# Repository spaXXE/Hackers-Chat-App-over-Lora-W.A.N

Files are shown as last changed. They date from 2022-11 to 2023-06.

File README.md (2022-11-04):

# Under rigorous Development...

***
### Watch out for exclusive tech. coming your way😎!

***

```py
    import time 

    def development():
        
        while 1:
            time.delay()
            break # DISCLAIMER: Heads up, will break soon...

    development()
```
***

***

   ### As an appetiser, we humbly offer you.....

***

## The Project's Structure.

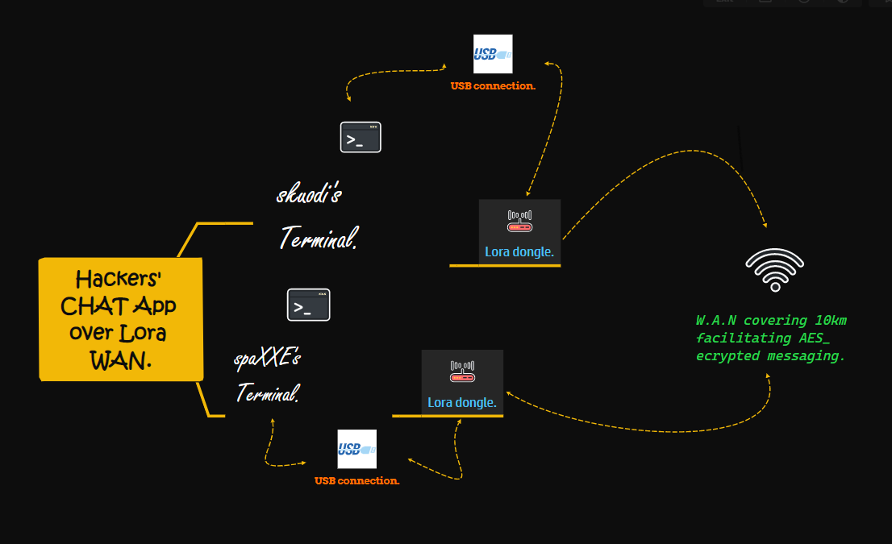
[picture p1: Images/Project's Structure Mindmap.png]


## The Sofware's Components and Structure Model.

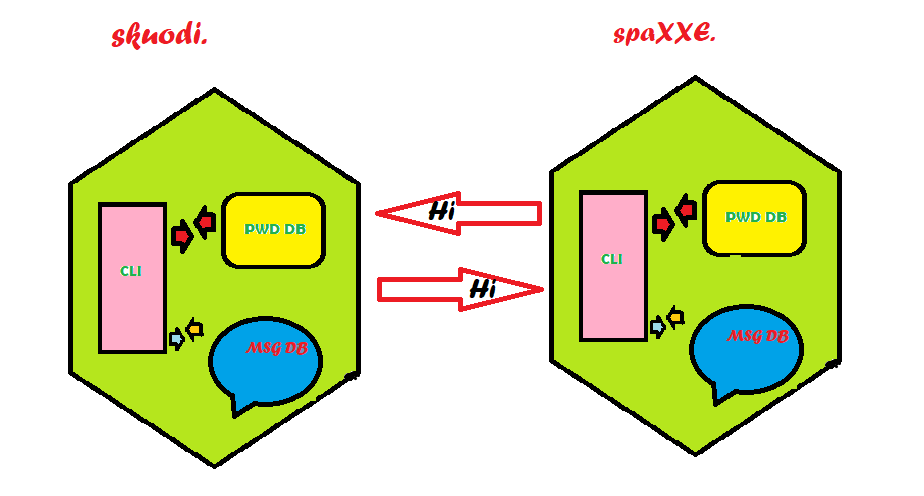
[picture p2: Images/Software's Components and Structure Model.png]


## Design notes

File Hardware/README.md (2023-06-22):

# LoRa Dongle

The hardware is a USB 2.0 fullspeed device with an STM32F042K6 MCU and 433MHz LoRa module based on the SX1278. Onboard EEPROM memory provides persistent storage of received messages and buffering of sent messages that have not been acknowledged to have been received by the sender.

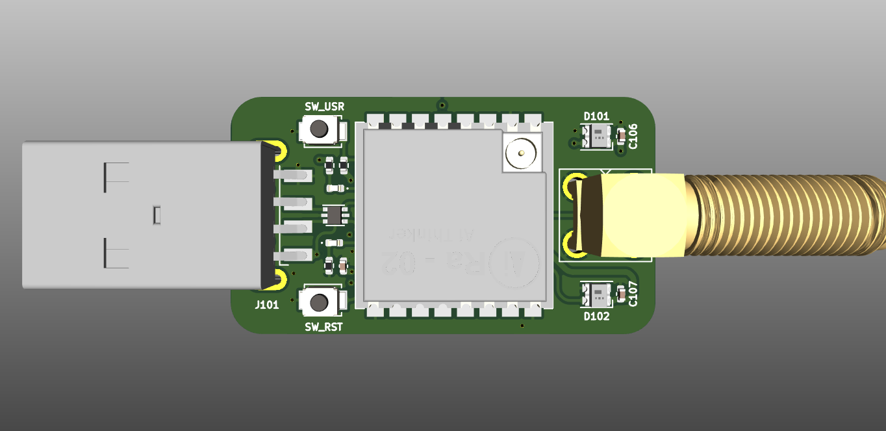
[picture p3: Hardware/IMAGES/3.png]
LoRa Dongle Top


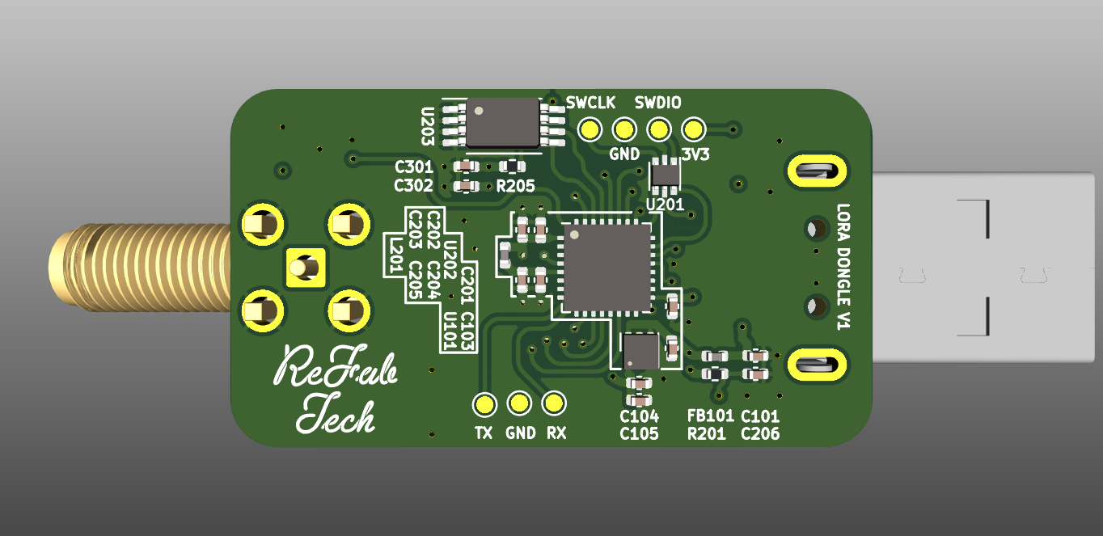
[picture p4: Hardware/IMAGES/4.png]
LoRa Dongle Top LoRa Dongle Bottom


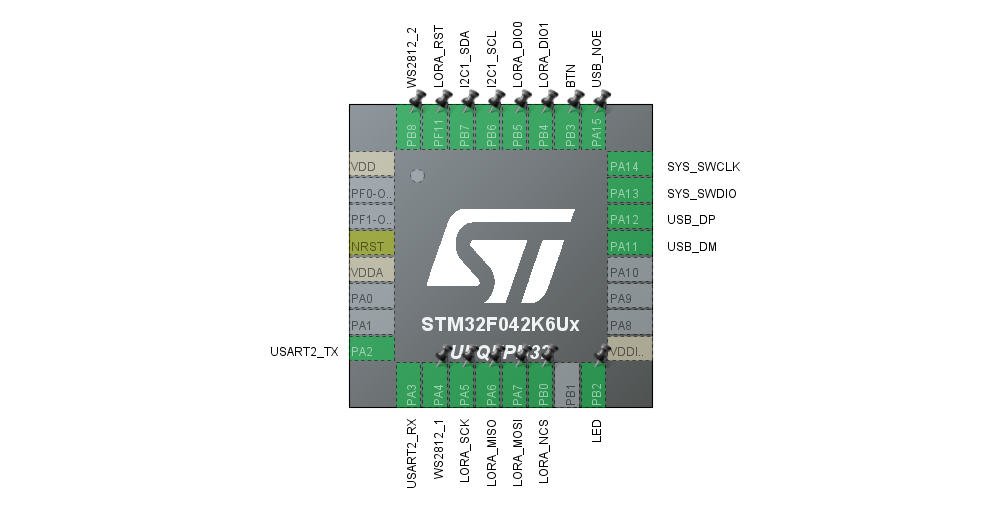
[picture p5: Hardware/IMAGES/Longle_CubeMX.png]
LoRa Dongle Top LoRa Dongle STM32 Pinout


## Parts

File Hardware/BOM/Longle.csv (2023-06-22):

Reference | Value | Footprint | MANUFACTURER | MPN | UNIT PRICE | VENDOR | Qty | TOTAL
AE301 | Antenna_Shield | Connector_Coaxial:SMA_Amphenol_901-143_Horizontal | BAT WIRELESS | BWSMA-KWE-Z001 | 0.4407 | LCSC | 1 | 0.4407
C101-C104, C203, C204, C206, C301 | 2u2 | Capacitor_SMD:C_0402_1005Metric | Samsung Electro-Mechanics | CL05A225MP5NSNC | 0.0038 | LCSC | 8 | 0.0304
C105-C107, C201, C202, C205, C302 | 100n | Capacitor_SMD:C_0402_1005Metric | CCTC | TCC0402X7R104K160AT | 0.0009 | LCSC | 7 | 0.0063
D101, D102 | WS2812B | LED_SMD:LED_WS2812B-2020_PLCC4_2.0x2.0mm | XINGLIGHT | XL-2020RGBC-WS2812B | 0.0738 | LCSC | 2 | 0.1476
D201 | LED_O | LED_SMD:LED_0402_1005Metric | XINGLIGHT | XL-1005UOC | 0.01 | LCSC | 1 | 0.01
D202 | LED_B | LED_SMD:LED_0402_1005Metric | XINGLIGHT | XL-1005UBC | 0.066 | LCSC | 1 | 0.066
FB101 | 220R@100MHz 1A | Inductor_SMD:L_0402_1005Metric | Sunlord | GZ0603D221TF | 0.0046 | LCSC | 1 | 0.0046
J101 | USB_A | Connector_USB:USB_A_CNCTech_1001-011-01101_Horizontal | SHOU HAN | AM 180° | 0.0394 | LCSC | 1 | 0.0394
L201 | 10u | Inductor_SMD:L_0402_1005Metric | Samsung Electro-Mechanics | CL05A106MP5NUNC | 0.0119 | LCSC | 1 | 0.0119
R201, R202, R205 | 10K 0.1% | Resistor_SMD:R_0402_1005Metric | YAGEO | RT0402BRE0710KL | 0.0212 | LCSC | 3 | 0.0636
R203, R204 | 1K 0.1% | Resistor_SMD:R_0402_1005Metric | YAGEO | RT0402BRD071KL | 0.0222 | LCSC | 2 | 0.0444
SW201 | SW_RST | Button_Switch_SMD:SW_SPST_B3U-1000P | Omron Electronics | B3U-1000P | 0.2648 | LCSC | 1 | 0.2648
SW202 | SW_USER | Button_Switch_SMD:SW_SPST_B3U-1000P | Omron Electronics | B3U-1000P | 0.2648 | LCSC | 1 | 0.2648
U101 | TLV75533PDRV | Package_SON:WSON-6-1EP_2x2mm_P0.65mm_EP1x1.6mm | Texas Instruments | TLV75533PDRVR | 0.2832 | LCSC | 1 | 0.2832
U102, U201 | USBLC6-2P6 | Package_TO_SOT_SMD:SOT-666 | TECH PUBLIC | USBLC6-2P6 | 0.1158 | LCSC | 2 | 0.2316
U202 | STM32F042K6Ux | Package_DFN_QFN:QFN-32-1EP_5x5mm_P0.5mm_EP3.45x3.45mm | STMicroelectronics | STM32F042K6U6TR | 3.4348 | LCSC | 1 | 3.4348
U203 | 24LC1025 | Package_SO:TSSOP-8_4.4x3mm_P0.65mm | FMD(Fremont Micro Devices) | FT24C1024A-TTR-T | 0.5521 | LCSC | 1 | 0.5521
U301 | Ai-Thinker-Ra-01 | RF_Module:Ai-Thinker-Ra-01-LoRa | Ai-Thinker | Ra-01SC-I | 3.5001 | LCSC | 1 | 3.5001
 |  |  |  |  |  |  | 36 | 9.3963

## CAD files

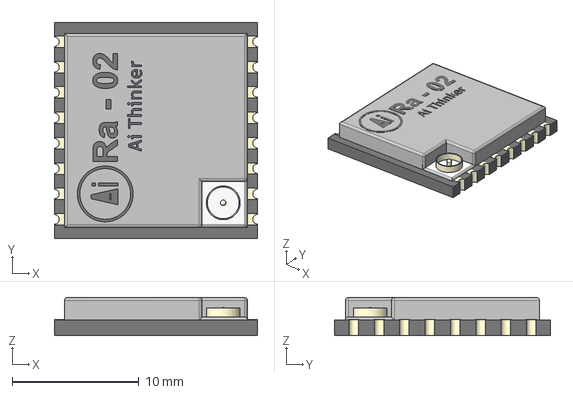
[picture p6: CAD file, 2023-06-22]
Hardware/3D/LoRa_Module_RA-02_AiThinker.step
16.0 x 17.0 x 3.03 mm

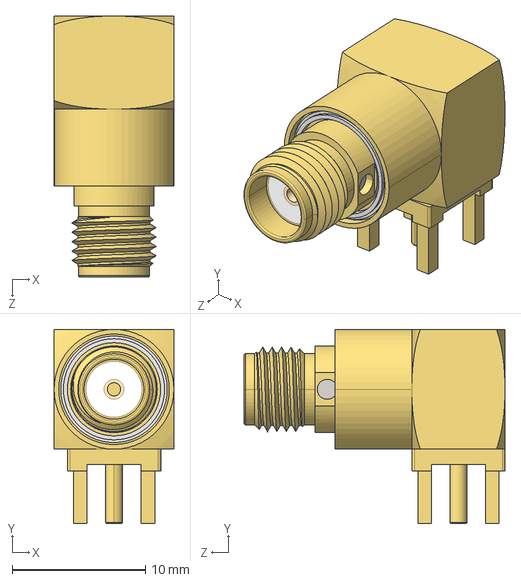
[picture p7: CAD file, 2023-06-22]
Hardware/3D/SMA.STEP
9.00 x 14.6 x 19.6 mm

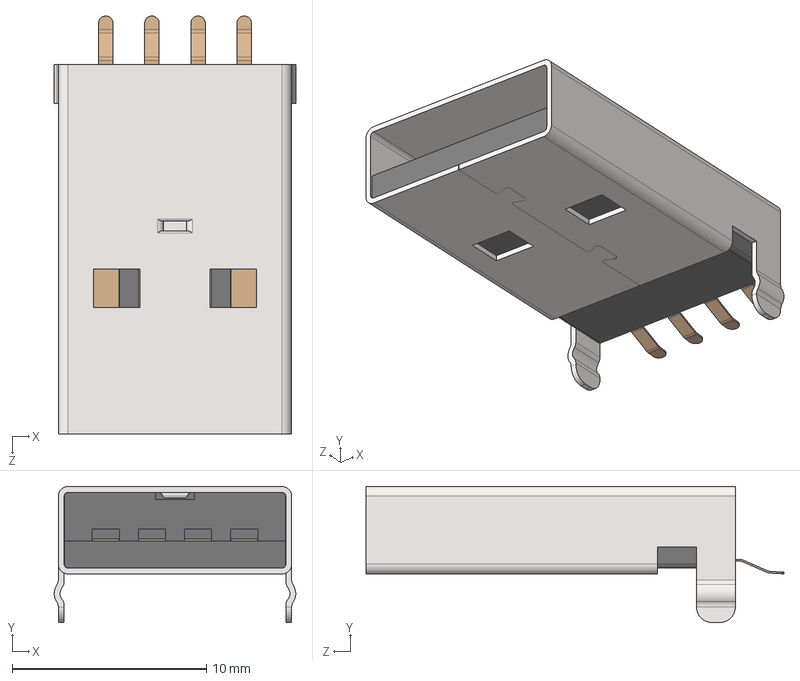
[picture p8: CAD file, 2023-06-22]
Hardware/3D/USB Connector Type A male, SMT.STEP
12.4 x 7.00 x 21.5 mm

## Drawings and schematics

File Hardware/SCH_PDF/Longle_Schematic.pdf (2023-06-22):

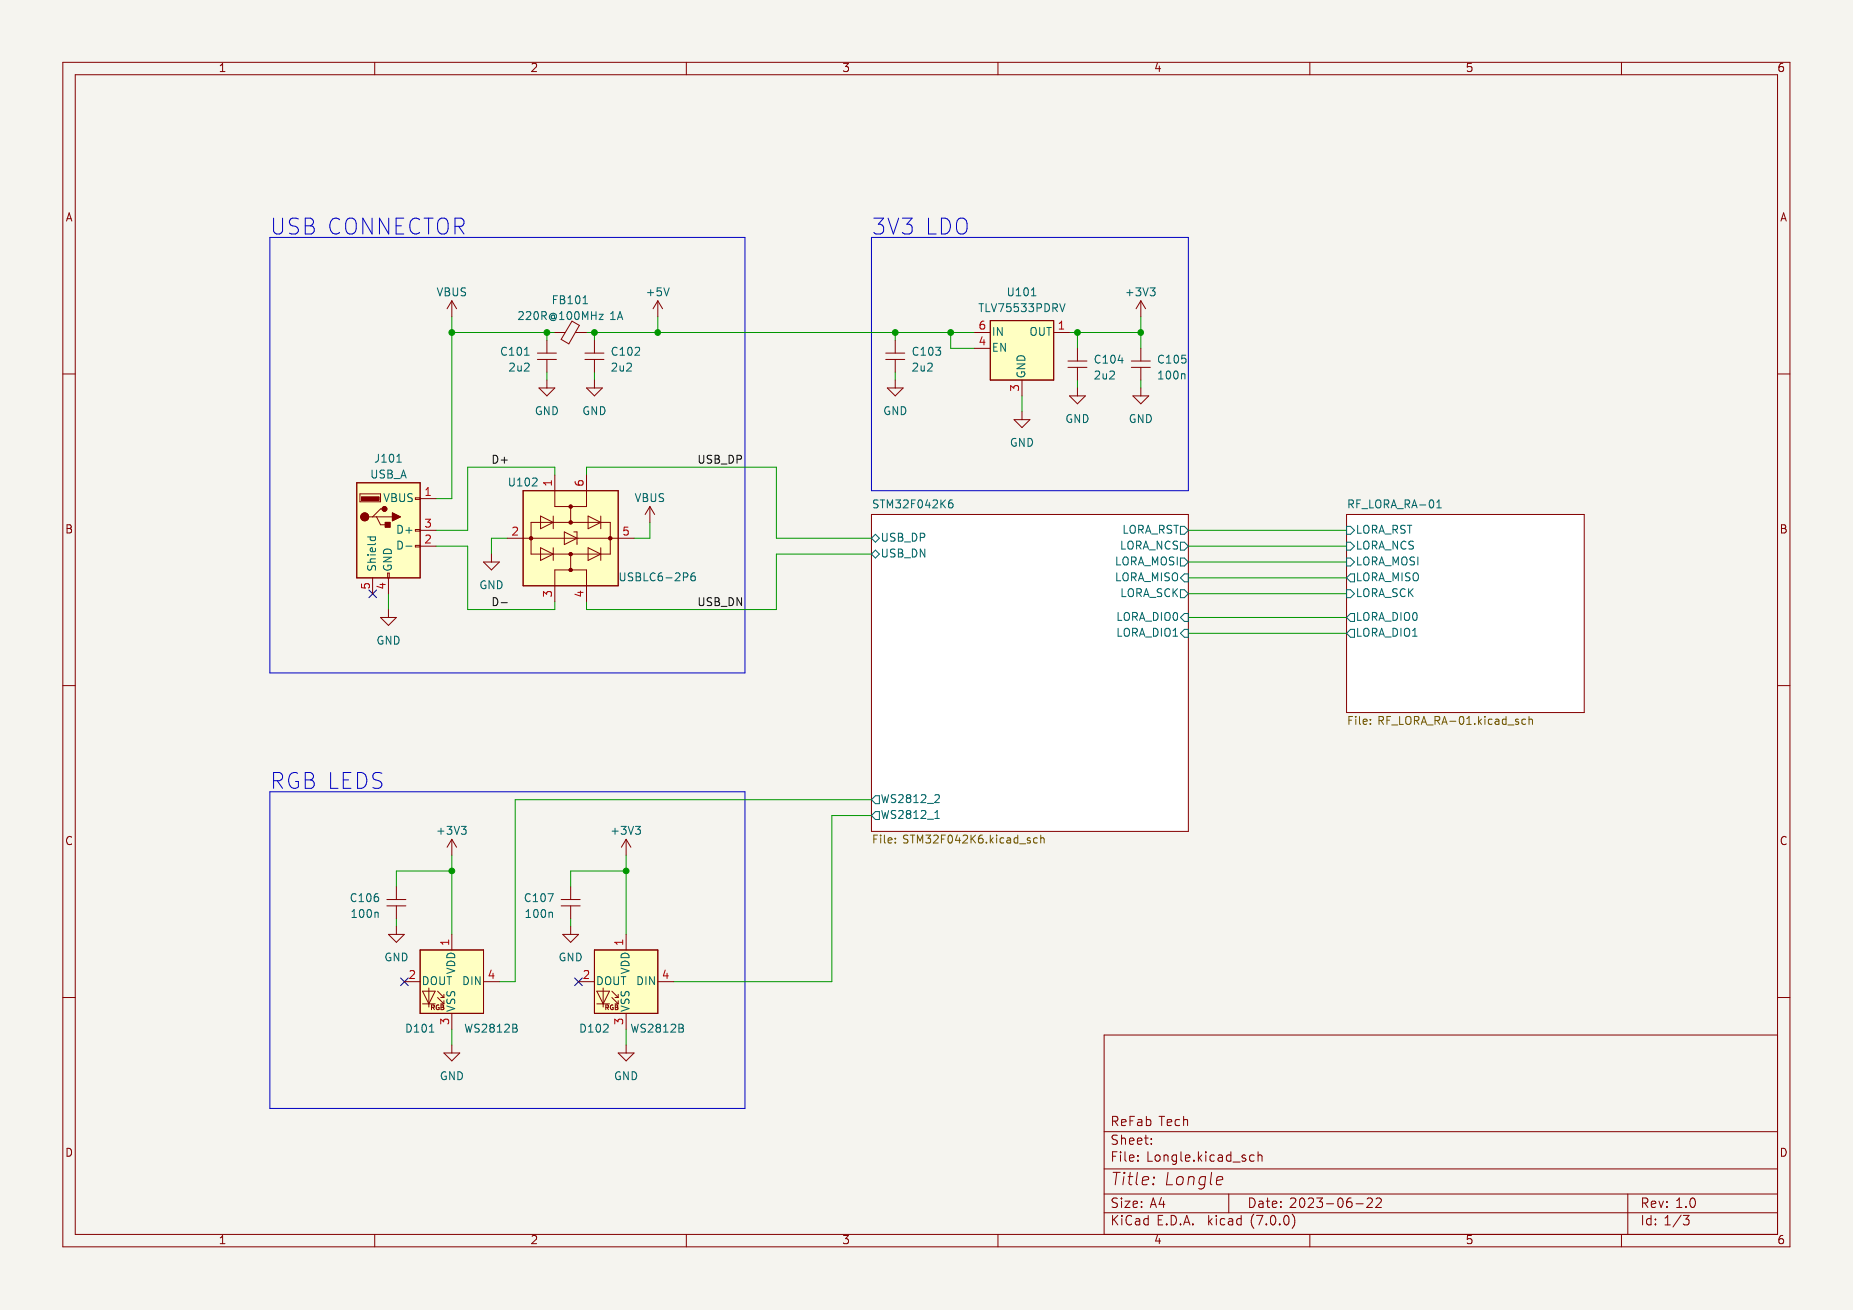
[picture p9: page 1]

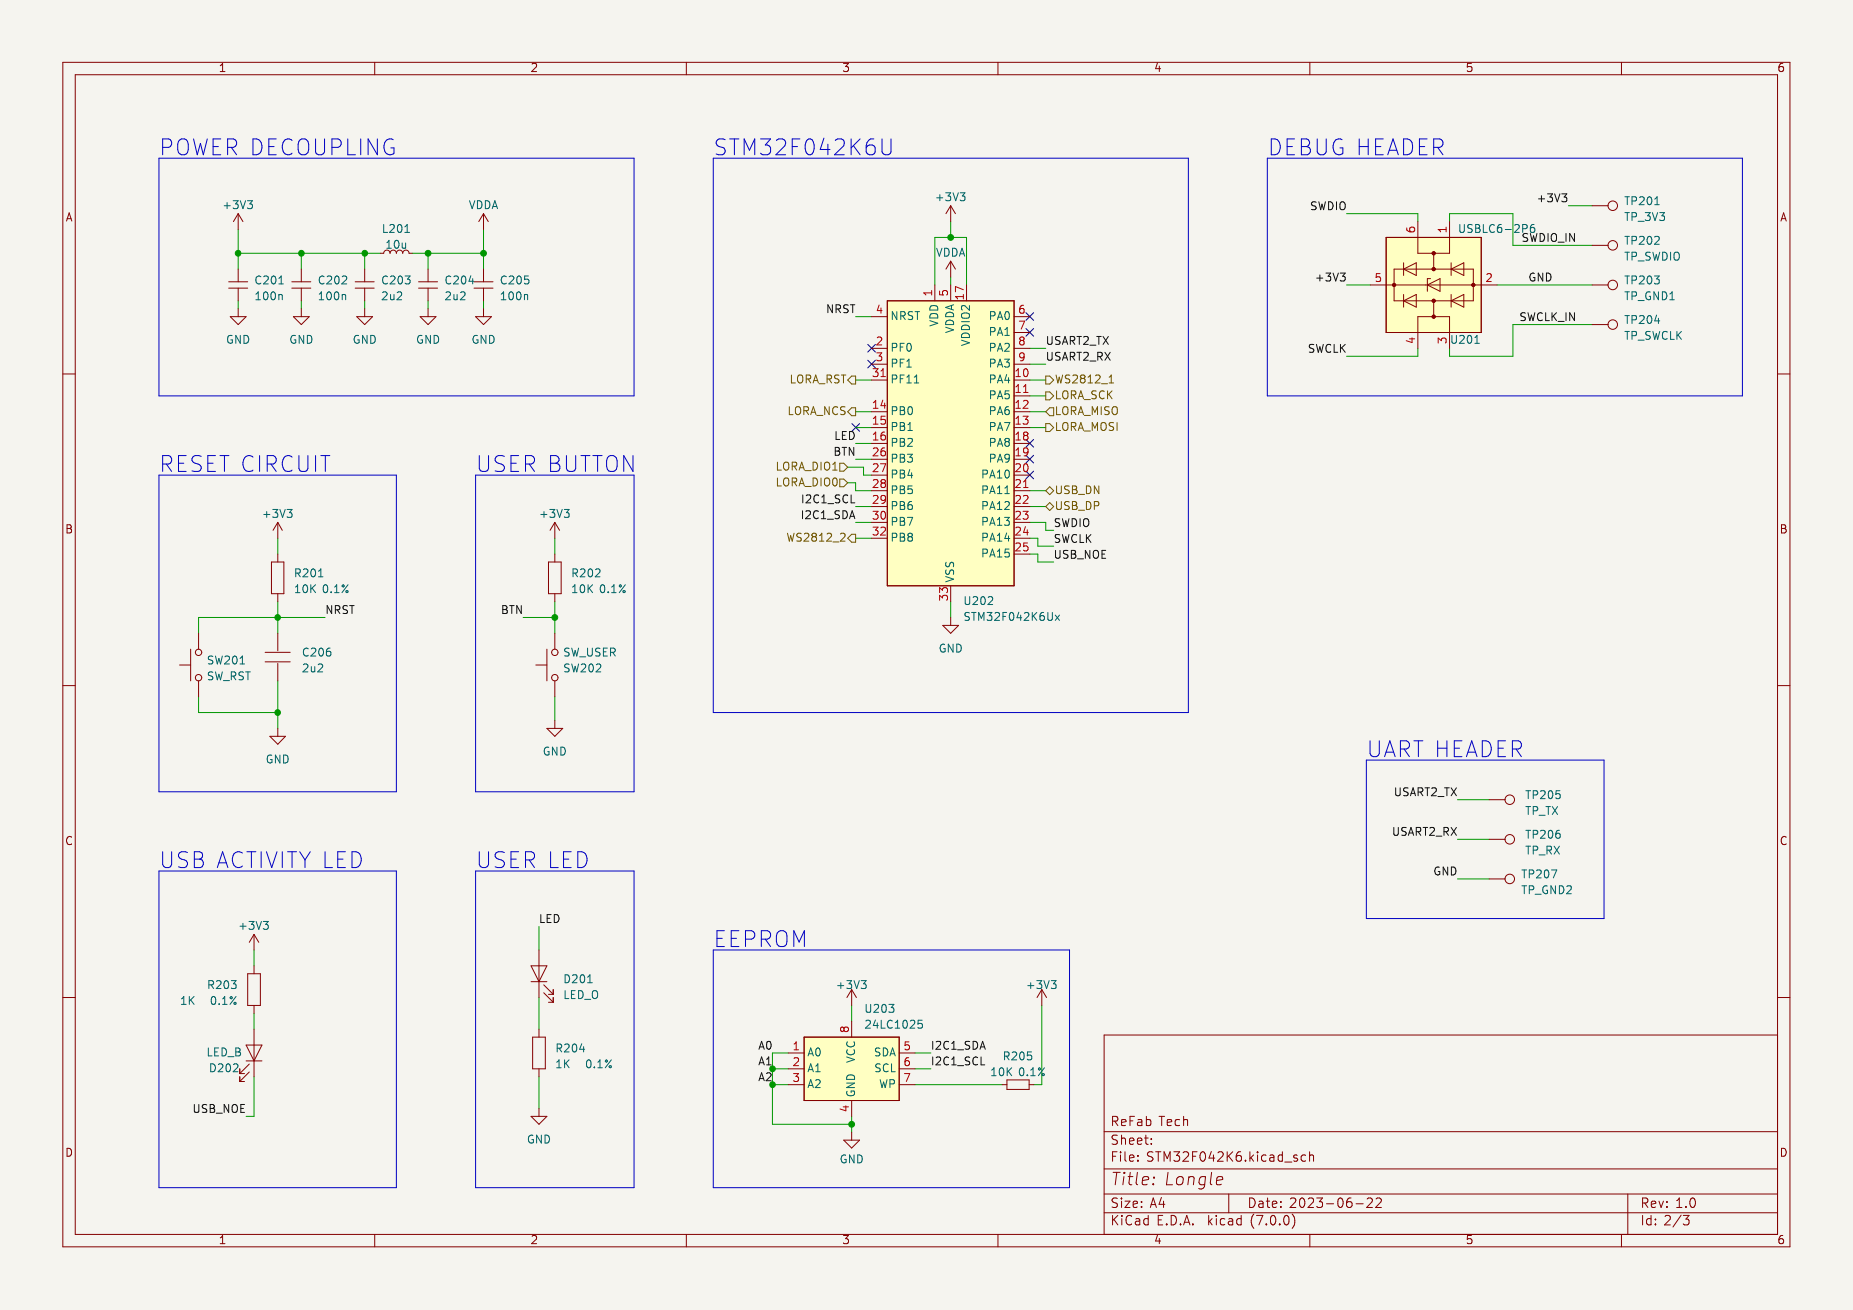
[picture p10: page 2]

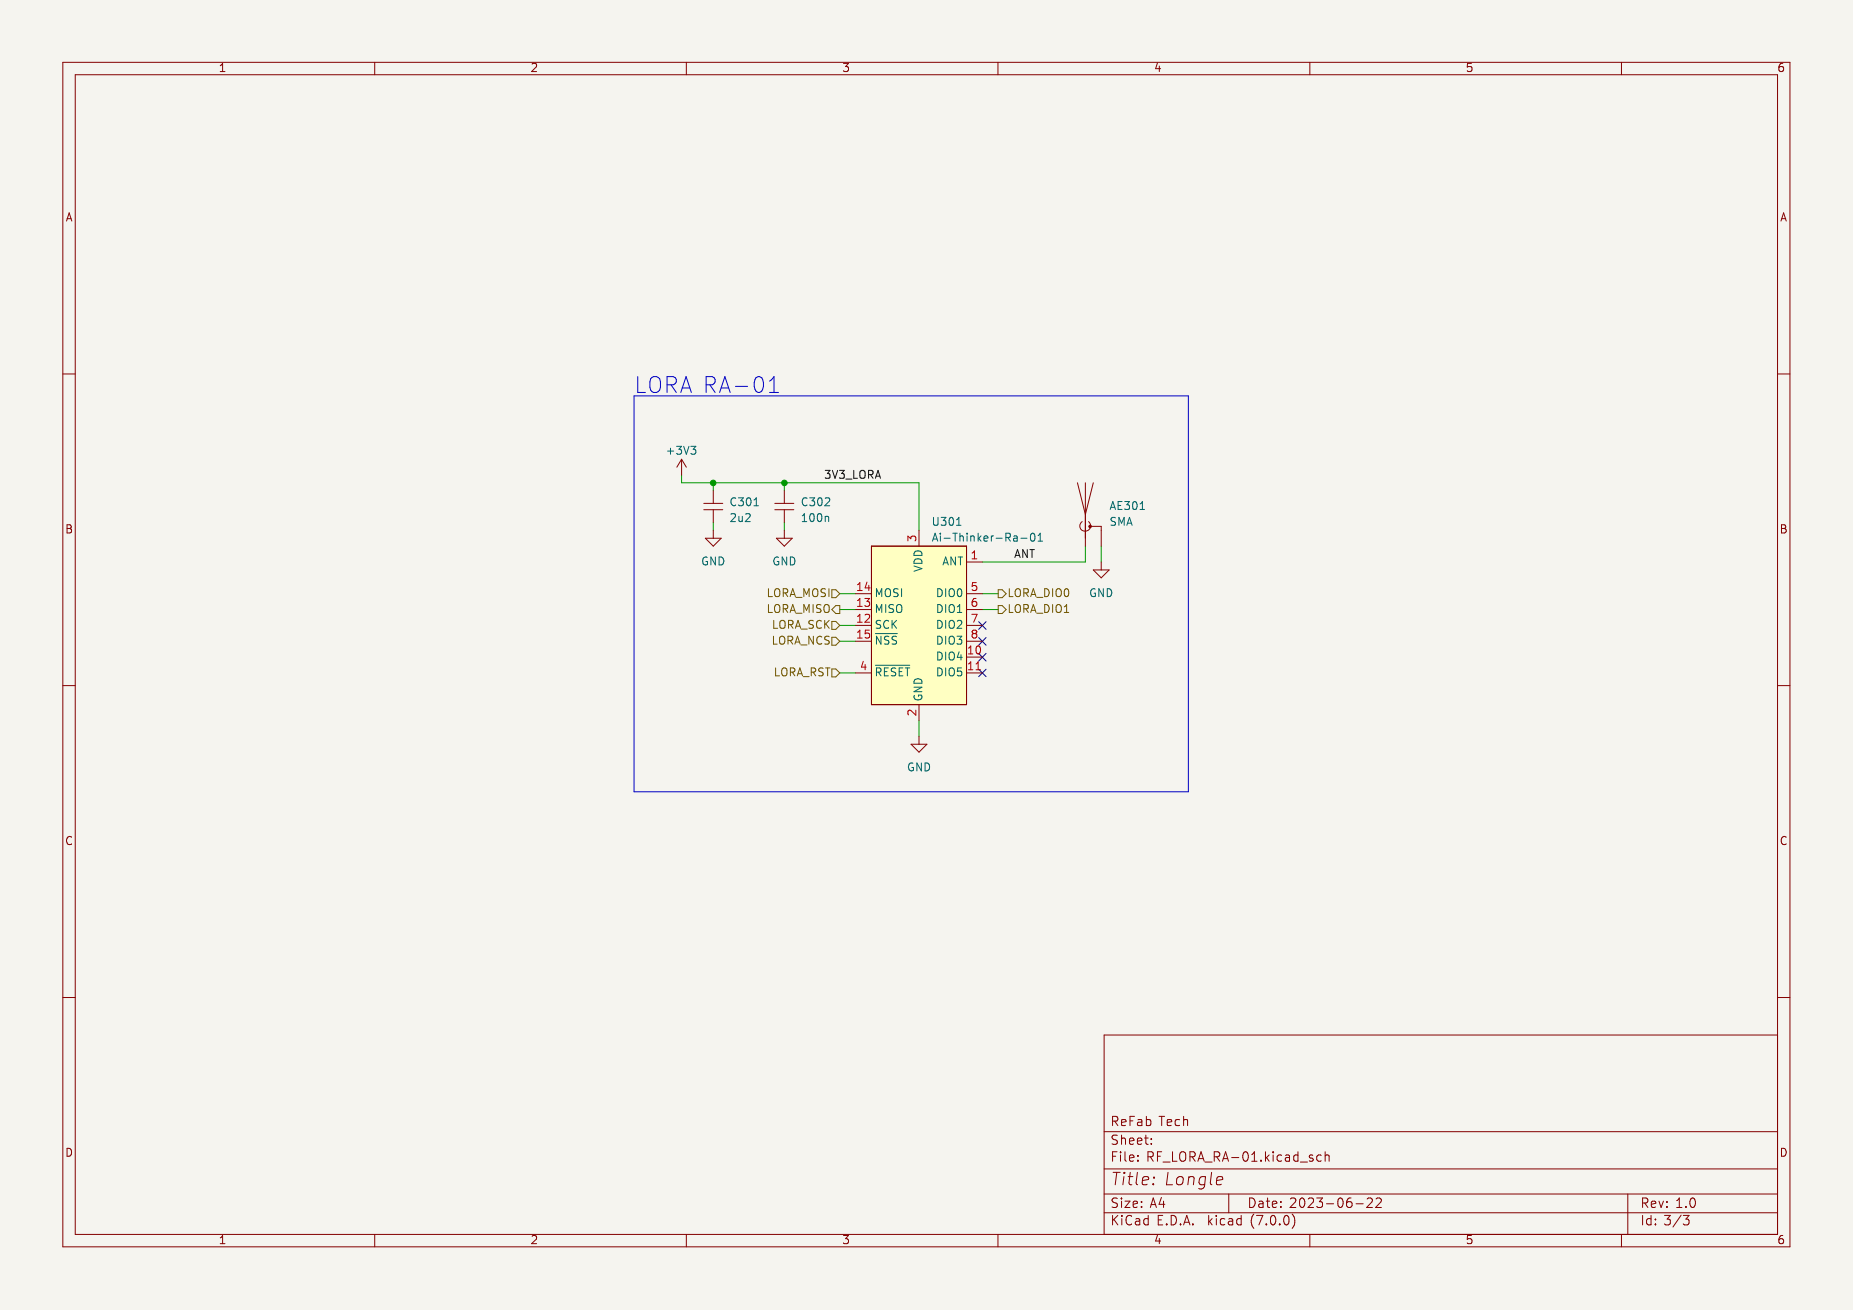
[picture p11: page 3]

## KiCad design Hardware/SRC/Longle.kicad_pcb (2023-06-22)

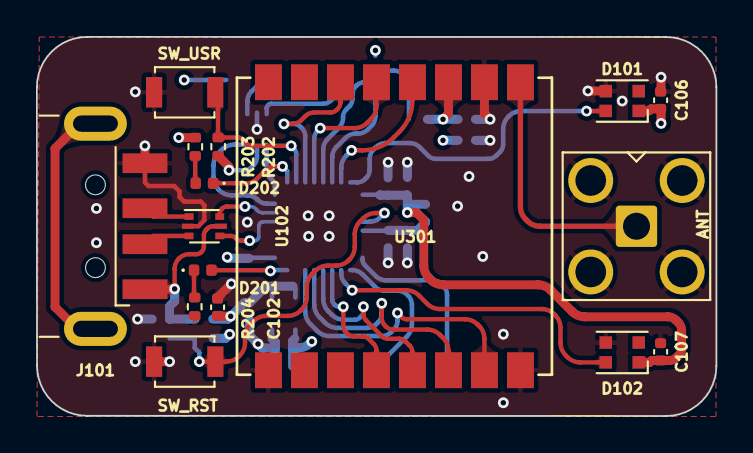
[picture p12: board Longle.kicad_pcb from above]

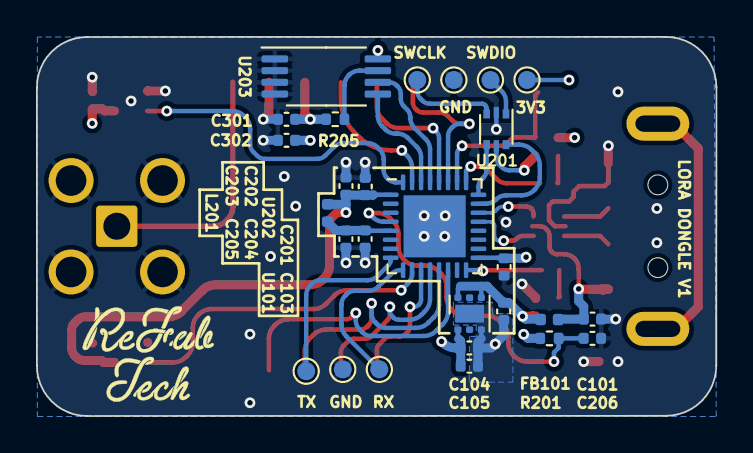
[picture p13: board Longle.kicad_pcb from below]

Board: 4 copper layers, 37.7 x 21.1 mm, 43 parts (27 on the bottom side), 34 nets.

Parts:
AE301: Antenna_Shield; SMA_Amphenol_901-143_Horizontal
C101, C102, C103, C104, C203, C204, C206, C301: 2u2; C_0402_1005Metric
C105, C106, C107, C201, C202, C205, C302: 100n; C_0402_1005Metric
D101, D102: WS2812B; LED_WS2812B-2020_PLCC4_2.0x2.0mm
D201: LED_O; LED_0402_1005Metric
D202: LED_B; LED_0402_1005Metric
FB101: 220R@100MHz 1A; L_0402_1005Metric
J101: USB_A; USB_A_CNCTech_1001-011-01101_Horizontal
L201: 10u; L_0402_1005Metric
R201, R202, R205: 10K 0.1%; R_0402_1005Metric
R203, R204: 1K 0.1%; R_0402_1005Metric
SW201: SW_RST; SW_SPST_B3U-1000P
SW202: SW_USER; SW_SPST_B3U-1000P
TP201: TP_3V3; TestPoint_Pad_D1.0mm
TP202: TP_SWDIO; TestPoint_Pad_D1.0mm
TP203: TP_GND1; TestPoint_Pad_D1.0mm
TP204: TP_SWCLK; TestPoint_Pad_D1.0mm
TP205: TP_TX; TestPoint_Pad_D1.0mm
TP206: TP_RX; TestPoint_Pad_D1.0mm
TP207: TP_GND2; TestPoint_Pad_D1.0mm
U101: TLV75533PDRV; WSON-6-1EP_2x2mm_P0.65mm_EP1x1.6mm
U102, U201: USBLC6-2P6; SOT-666
U202: STM32F042K6Ux; QFN-32-1EP_5x5mm_P0.5mm_EP3.45x3.45mm
U203: 24LC1025; TSSOP-8_4.4x3mm_P0.65mm
U301: Ai-Thinker-Ra-01; Ai-Thinker-Ra-01-LoRa

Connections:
+3V3: C104.1, C105.1, C106.1, C107.1, C201.1, C202.1, C203.1, C301.1, C302.1, D101.1 (VDD), D102.1 (VDD), L201.1, R201.1, R202.2, R203.2, R205.1, TP201.1, U101.1 (OUT), U201.5 (VBUS), U202.1 (VDD), U202.17 (VDDIO2), U203.8 (VCC), U301.3 (VDD)
+5V: C102.1, C103.1, FB101.2, U101.4 (EN), U101.6 (IN)
/D+: J101.3 (D+), U102.1 (I/O1)
/D-: J101.2 (D-), U102.3 (I/O2)
/RF_LORA_RA-01/ANT: AE301.1 (A), U301.1 (ANT)
/RF_LORA_RA-01/LORA_DIO0: U202.28 (PB5), U301.5 (DIO0)
/RF_LORA_RA-01/LORA_DIO1: U202.27 (PB4), U301.6 (DIO1)
/RF_LORA_RA-01/LORA_MISO: U202.12 (PA6), U301.13 (MISO)
/RF_LORA_RA-01/LORA_MOSI: U202.13 (PA7), U301.14 (MOSI)
/RF_LORA_RA-01/LORA_NCS: U202.14 (PB0), U301.15 (~NSS)
/RF_LORA_RA-01/LORA_RST: U202.31 (PF11), U301.4 (~RESET)
/RF_LORA_RA-01/LORA_SCK: U202.11 (PA5), U301.12 (SCK)
/STM32F042K6/BTN: R202.1, SW202.1, U202.26 (PB3)
/STM32F042K6/I2C1_SCL: U202.29 (PB6), U203.6 (SCL)
/STM32F042K6/I2C1_SDA: U202.30 (PB7), U203.5 (SDA)
/STM32F042K6/LED: D201.2 (A), U202.16 (PB2)
/STM32F042K6/NRST: C206.1, R201.2, SW201.2, U202.4 (NRST)
/STM32F042K6/SWCLK: U201.4 (I/O2), U202.24 (PA14)
/STM32F042K6/SWCLK_IN: TP204.1, U201.3 (I/O2)
/STM32F042K6/SWDIO: U201.6 (I/O1), U202.23 (PA13)
/STM32F042K6/SWDIO_IN: TP202.1, U201.1 (I/O1)
/STM32F042K6/USART2_RX: TP206.1, U202.9 (PA3)
/STM32F042K6/USART2_TX: TP205.1, U202.8 (PA2)
/STM32F042K6/USB_NOE: D202.1 (K), U202.25 (PA15)
/STM32F042K6/WS2812_1: D102.4 (DIN), U202.10 (PA4)
/STM32F042K6/WS2812_2: D101.4 (DIN), U202.32 (PB8)
/USB_DN: U102.4 (I/O2), U202.21 (PA11)
/USB_DP: U102.6 (I/O1), U202.22 (PA12)
GND: AE301.2 (Shield), C101.2, C102.2, C103.2, C104.2, C105.2, C106.2, C107.2, C201.2, C202.2, C203.2, C204.2, C205.2, C206.2, C301.2, C302.2, D101.3 (VSS), D102.3 (VSS), J101.4 (GND), R204.1, SW201.1, SW202.2, TP203.1, TP207.1, U101.3 (GND), U101.7 (GND), U102.2 (GND), U201.2 (GND), U202.33 (VSS), U203.1 (A0), U203.2 (A1), U203.3 (A2), U203.4 (GND), U301.2 (GND), U301.9 (GND), U301.16 (GND)
unnamed: D201.1 (K), R204.2
unnamed: D202.2 (A), R203.1
unnamed: R205.2, U203.7 (WP)
VBUS: C101.1, FB101.1, J101.1 (VBUS), U102.5 (VBUS)
VDDA: C204.1, C205.1, L201.2, U202.5 (VDDA)

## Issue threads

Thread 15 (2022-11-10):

Adding an Issue to the Project Board tutorial.

spaXXE, 2022-11-10:
[ ] some undone action here.
[✓] some done action here.

Closed 2022-11-10.

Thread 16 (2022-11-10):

Adding an issue to the project board tutorial.

spaXXE, 2022-11-10:

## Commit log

2023-06-22 Added dongle hardware files
    [LoRa_Module_RA-02_AiThinker.step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]
2023-06-22 Added STM32 Pinout
